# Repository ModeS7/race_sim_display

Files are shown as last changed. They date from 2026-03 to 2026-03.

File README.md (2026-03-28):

# Forza Horizon 4 Telemetry Dashboard — ESP32-2432S028 (CYD)

Real-time racing dashboard on the ESP32-2432S028 "Cheap Yellow Display" that receives Forza Horizon 4 UDP telemetry over WiFi and renders live data on the built-in 320x240 TFT.

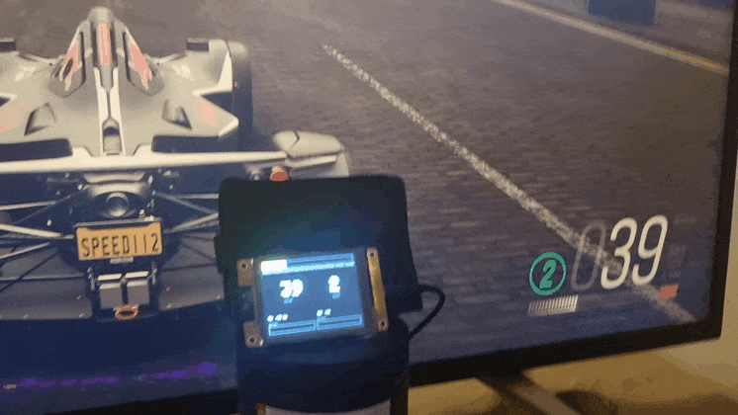
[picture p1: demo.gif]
Dashboard Demo


## Features

- **Multi-screen dashboard** — swipe left/right between screens:
  - **Race Dash** — large 7-segment gear indicator, speed, RPM bar with color zones, shift lights, position, pedal bars, lap times
  - **Data Dash** — same core layout plus large current lap timer, best/last lap comparison
  - **Lap Info** — detailed lap times, race position, speed and gear
  - **Settings** — toggle metric/imperial, adjust brightness, tune shift flash threshold, save to flash
- **Full-screen shift flash** — screen flashes red with "SHIFT!" at configurable RPM threshold, alternating with the live dashboard so you never lose data
- **7-segment gear display** — large custom-drawn gear indicator in the center of the screen
- **9-segment shift light bar** — green/yellow/red zones with configurable thresholds
- **Physical RGB LED shift light** — onboard LED mirrors the shift state (green → yellow → red → flashing)
- **Touch navigation** — tap left/right half of screen to switch between screens
- **Persistent settings** — saved to ESP32 NVS flash, survives reboots
- **Styled UI** — Race Stripe boot screen, Pit Lane animated waiting screen with scanning dots

## Hardware

- **Board**: ESP32-2432S028 (aka "Cheap Yellow Display" / CYD)
- **Display**: 2.8" 320x240 ILI9341 TFT (SPI/HSPI)
- **Touch**: XPT2046 resistive touchscreen (separate SPI/VSPI)
- **Onboard RGB LED**: pins 4 (R), 16 (G), 17 (B) — active LOW

## Setup

### 1. Install PlatformIO

If you don't have PlatformIO, install it via pip:

```bash
python -m venv .venv

# Windows
.venv\Scripts\activate

# Linux/Mac
source .venv/bin/activate

pip install platformio
```

### 2. WiFi Credentials

Copy the template and fill in your WiFi details:

```bash
cp src/wifi_credentials.h.template src/wifi_credentials.h
```

Edit `src/wifi_credentials.h`:

```cpp
#define DEFAULT_WIFI_SSID "YOUR_SSID"
#define DEFAULT_WIFI_PASS "YOUR_PASSWORD"
```

### 3. Build and Flash

Connect the CYD via USB and run:

```bash
pio run -t upload
```

If the upload fails mid-way, try a different USB cable or port. Hold the BOOT button on the CYD during upload if it won't connect.

### 4. Configure Forza Horizon 4

1. The CYD will show its IP address on the waiting screen after connecting to WiFi
2. Launch FH4, go to **Settings > HUD & Gameplay**
3. Scroll to **Data Out**
4. Set **Data Out** to **ON**
5. Set **Data Out IP Address** to the IP shown on the CYD
6. Set **Data Out Port** to `5300`
7. Start driving — the dashboard appears automatically

## Project Structure

```
src/
  main.cpp              - Setup, WiFi, screen manager, boot/waiting screens
  telemetry.h/cpp       - UDP listener, FH4 packet parsing, TelemetryData struct
  display.h/cpp         - TFT init, LED control, page dots, ScreenBase interface
  touch.h/cpp           - XPT2046 touch on VSPI, debounced edge detection
  settings.h/cpp        - Persistent settings via ESP32 Preferences (NVS)
  seg7.h/cpp            - Custom 7-segment digit renderer
  screen_dash.h/cpp     - Race Dash screen (gear, speed, RPM, position, pedals, laps)
  screen_dash_ext.h/cpp - Data Dash screen (adds large lap timer, best/last comparison)
  screen_laps.h/cpp     - Lap times detail screen
  screen_settings.h/cpp - Settings screen with touch controls
  wifi_credentials.h            - Your WiFi credentials (gitignored)
  wifi_credentials.h.template   - Template for credentials
```

## Troubleshooting

### Screen stays white or shows wrong colors

The CYD ships with different display driver ICs depending on the batch:

| Variant | USB Ports | Driver Flag |
|---|---|---|
| v1/v2 (most common) | 1x micro-USB | `-DILI9341_2_DRIVER` (default) |
| v3 "2USB" | micro-USB + USB-C | `-DST7789_DRIVER` |

If the display doesn't work, edit `platformio.ini` and change the driver flag, then re-flash.

### Screen shows colors but no text

Make sure the font flags are present in `platformio.ini` build_flags:

```
-DLOAD_GLCD
-DLOAD_FONT2
-DLOAD_FONT4
-DLOAD_FONT6
-DLOAD_FONT7
-DLOAD_FONT8
-DLOAD_GFXFF
```

### No telemetry data

- ESP32 and PC/Xbox must be on the **same WiFi network**
- IP and port must match what the CYD displays on the waiting screen
- FH4 only sends data while **actively driving** (race, freeroam, etc.) — it pauses in menus
- The dashboard stays visible for 20 seconds after pausing/rewinding before returning to the waiting screen

### Touch not responding

The CYD's touchscreen uses separate SPI pins from the display. If touch doesn't work:
- Verify the XPT2046_Touchscreen library is installed (should be automatic via `lib_deps`)
- The touch coordinate mapping may need calibration for your specific board — adjust the `map()` values in `src/touch.cpp`

## Shift Light Thresholds

Configurable via the Settings screen (swipe to screen 4) or by editing defaults in `src/settings.cpp`:

| Zone | Default % | On-Screen | RGB LED |
|---|---|---|---|
| Green | 75% | Segments 1-4 green | Green |
| Yellow | 85% | Segments 5-7 yellow | Yellow (R+G) |
| Red | 92% | Segments 8-9 red | Solid red |
| Flash | 90% | Full screen red + "SHIFT!" | Flashing red |

The flash threshold can be adjusted in Settings from 85% to 97%.

## Powering from a Logitech G920 Racing Wheel

You can power the CYD directly from the G920's internal 5V rail — no separate USB cable needed. The wheel's PCB exposes 5V and GND on the button connector pads.

### Step 1: Open the wheel and solder power wires

Remove the back cover of the G920 wheel (6 screws). Locate the button connector pads on the PCB and solder two wires:

- **Red wire** → 5V pad
- **White wire** → GND pad

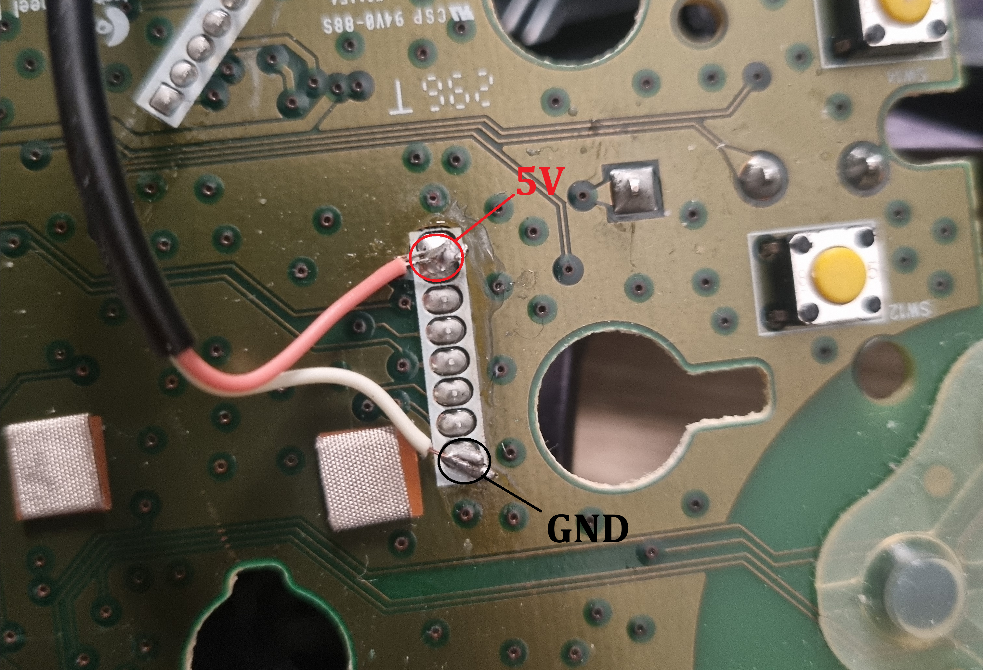
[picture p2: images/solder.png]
Solder points on G920 PCB — 5V and GND labeled


### Step 2: Route the cable out through the wheel

Feed the wires through one of the existing holes in the front face of the wheel. These OEM holes are perfect for routing a thin cable without any drilling.

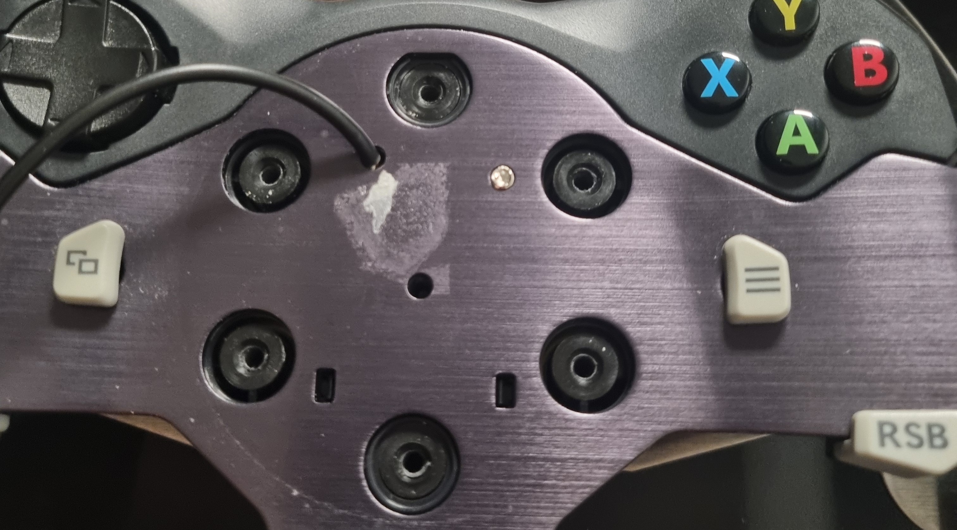
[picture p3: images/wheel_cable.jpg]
Cable routed through existing hole in the G920 wheel face


### Step 3: Mount the CYD with the 3D printed bracket

Print the bracket from the `3d/` folder (STL files included). The mount replaces the center cap on the G920 using the stock 6-bolt pattern (70mm PCD, 4.8mm holes) and extends upward into the top spoke area to hold the CYD at a natural viewing angle — similar to an F1 steering wheel display.

1. Place the **back part** of the mount over the center hub (the center cap was already removed in Step 1)
2. Connect the 5V and GND wires from Step 2 to the CYD's power pins
3. Seat the CYD into the back part
4. Press the inserts into the bolt holes to hold both parts in place
5. Place the **front part** over the CYD
6. Secure with the 6 stock center cap bolts + 4x M3x10mm screws for the CYD

### Wheel rim connector pinout (reference)

| Pin | Function |
|-----|---|
| 1 | GND |
| 2 | Button data (74HC165) |
| 3 | LED data (74HC595) |
| 4 | Clock |
| 5 | Latch |
| 6 | Parallel load |
| 7 | 5V |

## FH4 Telemetry Packet Format

The dashboard parses the 324-byte "Car Dash" UDP packet. Key offsets (FH4-specific, include the +12 byte Horizon shift):

| Offset | Type | Field |
|---|---|---|
| 0 | s32 | IsRaceOn |
| 8 | f32 | EngineMaxRpm |
| 12 | f32 | EngineIdleRpm |
| 16 | f32 | CurrentEngineRpm |
| 20 | f32 | AccelerationX |
| 24 | f32 | AccelerationY |
| 28 | f32 | AccelerationZ |
| 256 | f32 | Speed (m/s) |
| 260 | f32 | Power (watts) |
| 264 | f32 | Torque (Nm) |
| 284 | f32 | Boost (atmospheres) |
| 296 | f32 | BestLap (seconds) |
| 300 | f32 | LastLap (seconds) |
| 304 | f32 | CurrentLap (seconds) |
| 314 | u8 | RacePosition |
| 315 | u8 | Accel (0-255) |
| 316 | u8 | Brake (0-255) |
| 319 | u8 | Gear (0=R, 1-10) |

## License

MIT

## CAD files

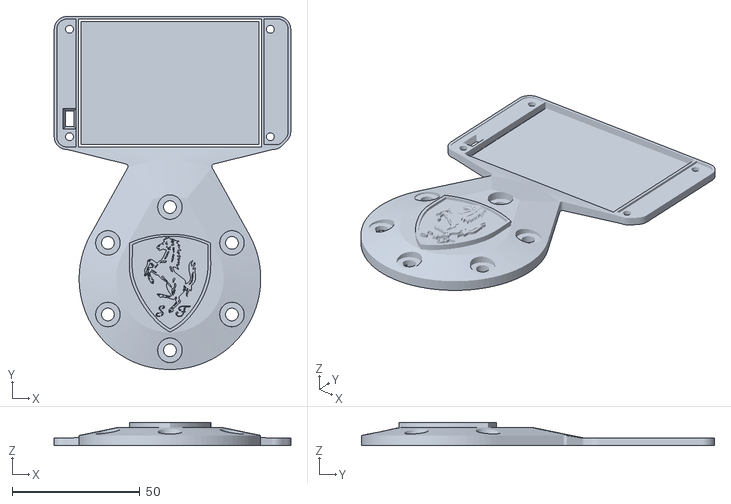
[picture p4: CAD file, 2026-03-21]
3D_mount/dash_screen_front.stl
92.5 x 138.0 x 9.11

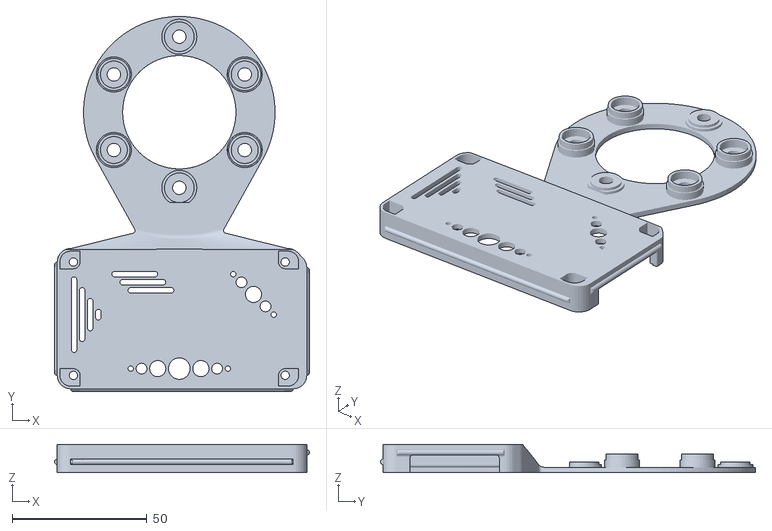
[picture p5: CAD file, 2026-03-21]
3D_mount/dash_screen_back.stl
94.5 x 139.0 x 10.5

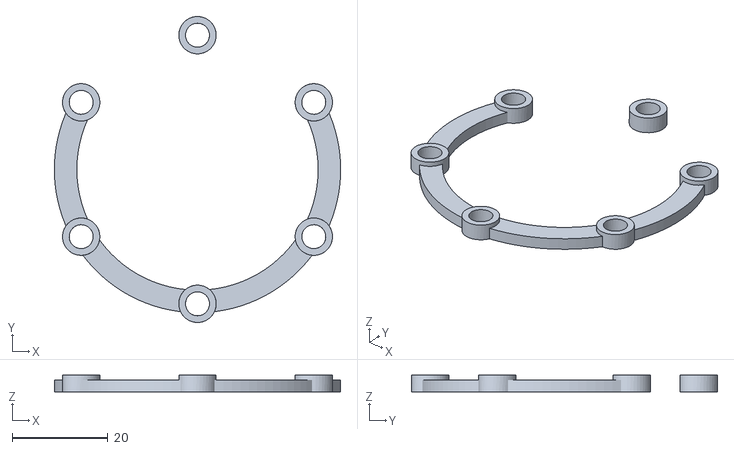
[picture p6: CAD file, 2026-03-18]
3D_mount/middle_insert.stl
59.7 x 63.8 x 3.50

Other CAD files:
3D_mount/dash_screen_back.f3d
3D_mount/dash_screen_front.f3d
3D_mount/middle_insert.f3d

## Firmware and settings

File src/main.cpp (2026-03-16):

#include <Arduino.h>
#include <WiFi.h>
#include "soc/soc.h"
#include "soc/rtc_cntl_reg.h"
#include "telemetry.h"
#include "display.h"
#include "touch.h"
#include "settings.h"
#include "screen_dash.h"
#include "screen_dash_ext.h"
#include "screen_laps.h"
#include "screen_settings.h"

// ── Screens ─────────────────────────────────────────────────────────────────
DashScreen      screenDash;
DashExtScreen   screenDashExt;
LapsScreen      screenLaps;
SettingsScreen  screenSettings;

ScreenBase* screens[] = { &screenDash, &screenDashExt, &screenLaps, &screenSettings };
const int NUM_SCREENS = 4;
int currentScreenIdx = 0;

// ── App state ───────────────────────────────────────────────────────────────
enum AppState { STATE_CONNECTING, STATE_WAITING, STATE_ACTIVE };
AppState appState = STATE_CONNECTING;

uint32_t lastDrawTime = 0;
uint32_t lastRaceOnTime = 0;
uint32_t waitingDotTimer = 0;
int waitingDotIdx = 0;

#define FRAME_INTERVAL_MS 33
#define RACE_OFF_TIMEOUT_MS 20000

// ── Helpers ─────────────────────────────────────────────────────────────────

void switchScreen(int newIdx) {
    screens[currentScreenIdx]->leave();
    currentScreenIdx = newIdx;
    screens[currentScreenIdx]->enter();
    drawPageDots(currentScreenIdx, NUM_SCREENS);
}

// ── Concept 4: Race Stripe — Boot/Connecting Screen ─────────────────────────
void drawConnectingScreen() {
    tft.fillScreen(TFT_BLACK);

    // Top and bottom red bars
    tft.fillRect(0, 0, 320, 6, TFT_RED);
    tft.fillRect(0, 234, 320, 6, TFT_RED);

    // Diagonal stripes
    uint16_t stripeCol = 0x1082;
    for (int i = 0; i < 3; i++) {
        int sx = 60 + i * 100;
        tft.fillTriangle(sx, 20, sx + 30, 20, sx + 10, 90, stripeCol);
        tft.fillTriangle(sx + 30, 20, sx + 10, 90, sx + 40, 90, stripeCol);
    }
    for (int i = 0; i < 3; i++) {
        int sx = 60 + i * 100;
        tft.fillTriangle(sx + 10, 145, sx + 40, 145, sx + 30, 215, stripeCol);
        tft.fillTriangle(sx + 40, 145, sx + 30, 215, sx + 60, 215, stripeCol);
    }

    // Title
    tft.setTextDatum(MC_DATUM);
    tft.setTextSize(3);
    tft.setTextColor(TFT_WHITE, TFT_BLACK);
    tft.drawString("FORZA", 160, 105);
    tft.setTextColor(TFT_RED, TFT_BLACK);
    tft.drawString("DASH", 160, 132);

    // Status
    tft.setTextSize(1);
    tft.setTextColor(TFT_DARKGREY, TFT_BLACK);
    tft.drawString("Connecting WiFi...", 160, 220);
}

void drawWifiFailed() {
    tft.fillScreen(TFT_BLACK);
    tft.fillRect(0, 0, 320, 6, TFT_RED);
    tft.fillRect(0, 234, 320, 6, TFT_RED);

    tft.setTextDatum(MC_DATUM);
    tft.setTextSize(3);
    tft.setTextColor(TFT_RED, TFT_BLACK);
    tft.drawString("WiFi FAILED", 160, 100);
    tft.setTextSize(1);
    tft.setTextColor(TFT_DARKGREY, TFT_BLACK);
    tft.drawString("Check SSID/password and reboot", 160, 140);
}

// ── Concept 1: Pit Lane — Waiting for Telemetry Screen ──────────────────────
void drawWaitingScreen() {
    tft.fillScreen(TFT_BLACK);

    // Cyan horizontal rules
    tft.drawFastHLine(20, 50, 280, TFT_CYAN);
    tft.drawFastHLine(20, 52, 280, TFT_CYAN);

    // Title
    tft.setTextDatum(MC_DATUM);
    tft.setTextSize(3);
    tft.setTextColor(TFT_WHITE, TFT_BLACK);
    tft.drawString("FORZA DASH", 160, 75);

    tft.drawFastHLine(20, 98, 280, TFT_CYAN);
    tft.drawFastHLine(20, 100, 280, TFT_CYAN);

    // Scanning dots (initial state)
    for (int i = 0; i < 4; i++) {
        int cx = 130 + i * 20;
        tft.drawCircle(cx, 120, 4, TFT_CYAN);
    }
    waitingDotIdx = 0;
    waitingDotTimer = millis();

    // Subtitle
    tft.setTextSize(1);
    tft.setTextColor(TFT_DARKGREY, TFT_BLACK);
    tft.drawString("Waiting for telemetry...", 160, 140);

    // IP box
    tft.drawRoundRect(60, 155, 200, 24, 4, TFT_CYAN);
    tft.setTextColor(TFT_CYAN, TFT_BLACK);
    String ipStr = WiFi.localIP().toString() + ":" + String(g_settings.udpPort);
    tft.drawString(ipStr, 160, 167);

    // Instructions
    tft.setTextColor(TFT_DARKGREY, TFT_BLACK);
    tft.drawString("Settings > HUD & Gameplay > Data Out", 160, 195);
}

void updateWaitingDots() {
    uint32_t now = millis();
    if (now - waitingDotTimer < 300) return;
    waitingDotTimer = now;

    // Clear previous dot
    int prevCx = 130 + waitingDotIdx * 20;
    tft.fillCircle(prevCx, 120, 4, TFT_BLACK);
    tft.drawCircle(prevCx, 120, 4, TFT_CYAN);

    // Advance
    waitingDotIdx = (waitingDotIdx + 1) % 4;

    // Fill current dot
    int cx = 130 + waitingDotIdx * 20;
    tft.fillCircle(cx, 120, 4, TFT_CYAN);
}

// ── Concept 3: Grid Menu — Screen Selection ─────────────────────────────────
#define MENU_BW 145
#define MENU_BH 90
#define MENU_X1 8
#define MENU_X2 167
#define MENU_Y1 28
#define MENU_Y2 124

void drawGridMenu() {
    tft.fillScreen(TFT_BLACK);

    // Header bar
    tft.fillRect(0, 0, 320, 22, 0x2104);
    tft.setTextDatum(TL_DATUM);
    tft.setTextSize(1);
    tft.setTextColor(TFT_WHITE, 0x2104);
    tft.drawString("FORZA DASH", 6, 7);
    tft.setTextDatum(TR_DATUM);
    tft.setTextColor(TFT_CYAN, 0x2104);
    String ip = WiFi.localIP().toString();
    tft.drawString(ip, 314, 7);

    // Box 1: DASHBOARD
    tft.drawRoundRect(MENU_X1, MENU_Y1, MENU_BW, MENU_BH, 6, TFT_CYAN);
    tft.fillTriangle(MENU_X1 + 55, MENU_Y1 + 20, MENU_X1 + 45, MENU_Y1 + 55,
                     MENU_X1 + 65, MENU_Y1 + 55, TFT_GREEN);
    tft.fillRect(MENU_X1 + 70, MENU_Y1 + 25, 8, 35, TFT_RED);
    tft.fillRect(MENU_X1 + 82, MENU_Y1 + 35, 8, 25, TFT_YELLOW);
    tft.setTextDatum(MC_DATUM);
    tft.setTextSize(1);
    tft.setTextColor(TFT_WHITE, TFT_BLACK);
    tft.drawString("DASHBOARD", MENU_X1 + MENU_BW / 2, MENU_Y1 + MENU_BH - 10);

    // Box 2: TELEMETRY
    tft.drawRoundRect(MENU_X2, MENU_Y1, MENU_BW, MENU_BH, 6, TFT_DARKGREY);
    tft.drawFastHLine(MENU_X2 + 40, MENU_Y1 + 55, 65, TFT_DARKGREY);
    tft.drawFastVLine(MENU_X2 + 40, MENU_Y1 + 20, 35, TFT_DARKGREY);
    tft.drawLine(MENU_X2 + 45, MENU_Y1 + 50, MENU_X2 + 60, MENU_Y1 + 30, TFT_CYAN);
    tft.drawLine(MENU_X2 + 60, MENU_Y1 + 30, MENU_X2 + 75, MENU_Y1 + 40, TFT_CYAN);
    tft.drawLine(MENU_X2 + 75, MENU_Y1 + 40, MENU_X2 + 95, MENU_Y1 + 25, TFT_CYAN);
    tft.setTextColor(TFT_WHITE, TFT_BLACK);
    tft.drawString("TELEMETRY", MENU_X2 + MENU_BW / 2, MENU_Y1 + MENU_BH - 10);

    // Box 3: LAPS
    tft.drawRoundRect(MENU_X1, MENU_Y2, MENU_BW, MENU_BH, 6, TFT_DARKGREY);
    for (int i = 0; i < 3; i++) {
        int ly = MENU_Y2 + 20 + i * 16;
        tft.fillCircle(MENU_X1 + 40, ly + 3, 2, TFT_GREEN);
        tft.drawFastHLine(MENU_X1 + 48, ly + 2, 50, TFT_DARKGREY);
    }
    tft.setTextColor(TFT_WHITE, TFT_BLACK);
    tft.drawString("LAPS", MENU_X1 + MENU_BW / 2, MENU_Y2 + MENU_BH - 10);

    // Box 4: SETTINGS
    tft.drawRoundRect(MENU_X2, MENU_Y2, MENU_BW, MENU_BH, 6, TFT_DARKGREY);
    int gcx = MENU_X2 + MENU_BW / 2, gcy = MENU_Y2 + 40;
    tft.drawCircle(gcx, gcy, 12, TFT_DARKGREY);
    tft.drawCircle(gcx, gcy, 6, TFT_WHITE);
    for (int a = 0; a < 360; a += 45) {
        float rad = a * DEG_TO_RAD;
        int tx = gcx + (int)(15 * cos(rad));
        int ty = gcy + (int)(15 * sin(rad));
        tft.fillRect(tx - 2, ty - 2, 4, 4, TFT_WHITE);
    }
    tft.setTextColor(TFT_WHITE, TFT_BLACK);
    tft.drawString("SETTINGS", MENU_X2 + MENU_BW / 2, MENU_Y2 + MENU_BH - 10);
}

int handleMenuTouch(int tx, int ty) {
    // Returns screen index (0-3) or -1 if no box hit
    if (ty >= MENU_Y1 && ty < MENU_Y1 + MENU_BH) {
        if (tx >= MENU_X1 && tx < MENU_X1 + MENU_BW) return 0;  // Dashboard
        if (tx >= MENU_X2 && tx < MENU_X2 + MENU_BW) return 1;  // Telemetry
    }
    if (ty >= MENU_Y2 && ty < MENU_Y2 + MENU_BH) {
        if (tx >= MENU_X1 && tx < MENU_X1 + MENU_BW) return 2;  // Laps
        if (tx >= MENU_X2 && tx < MENU_X2 + MENU_BW) return 3;  // Settings
    }
    return -1;
}

// ── Setup ───────────────────────────────────────────────────────────────────

void setup() {
    WRITE_PERI_REG(RTC_CNTL_BROWN_OUT_REG, 0);  // Disable brownout detector
    setCpuFrequencyMhz(80);                       // 80MHz = less current, WiFi still works

    Serial.begin(115200);
    settingsLoad();
    displayInit();
    touchInit();

    drawConnectingScreen();

    WiFi.mode(WIFI_STA);
    WiFi.begin(g_settings.wifiSSID, g_settings.wifiPass);

    uint32_t wifiStart = millis();
    while (WiFi.status() != WL_CONNECTED) {
        if (millis() - wifiStart > 15000) {
            drawWifiFailed();
            Serial.println("WiFi connection failed!");
            while (true) { delay(1000); }
        }
        delay(250);
    }

    Serial.print("Connected! IP: ");
    Serial.println(WiFi.localIP());

    // Lower WiFi TX power to reduce current spikes
    WiFi.setTxPower(WIFI_POWER_8_5dBm);
    WiFi.setSleep(true);  // Enable modem sleep between packets

    telemetryInit(g_settings.udpPort);

    appState = STATE_WAITING;
    drawWaitingScreen();
}

// ── Loop ────────────────────────────────────────────────────────────────────

void loop() {
    uint32_t now = millis();
    if (now - lastDrawTime < FRAME_INTERVAL_MS) return;
    lastDrawTime = now;

    TelemetryData data = telemetrySnapshot();

    // ── Waiting state (Pit Lane screen) ─────────────────────────────────
    if (appState == STATE_WAITING) {
        updateWaitingDots();
        if (data.isRaceOn == 1) {
            appState = STATE_ACTIVE;
            lastRaceOnTime = now;
            currentScreenIdx = 0;
            screens[0]->enter();
            drawPageDots(0, NUM_SCREENS);
        }
        return;
    }

    // ── Active state ────────────────────────────────────────────────────
    if (data.isRaceOn == 1) {
        lastRaceOnTime = now;
    } else if (now - lastRaceOnTime > RACE_OFF_TIMEOUT_MS) {
        screens[currentScreenIdx]->leave();
        appState = STATE_WAITING;
        setLED(false, false, false);
        drawWaitingScreen();
        return;
    }

    // ── Touch navigation ────────────────────────────────────────────────
    int tx, ty;
    if (touchGetXY(tx, ty)) {
        if (!screens[currentScreenIdx]->handleTouch(tx, ty)) {
            if (tx < 160) {
                switchScreen((currentScreenIdx - 1 + NUM_SCREENS) % NUM_SCREENS);
            } else {
                switchScreen((currentScreenIdx + 1) % NUM_SCREENS);
            }
        }
    }

    // ── Update current screen ───────────────────────────────────────────
    screens[currentScreenIdx]->update(data);
}

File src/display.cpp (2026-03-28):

#include "display.h"
#include "settings.h"

TFT_eSPI tft = TFT_eSPI();

static uint32_t lastBrightnessUpdate = 0;
static int smoothedLight = 2048;  // start mid-range

void displayInit() {
    pinMode(LED_R, OUTPUT);
    pinMode(LED_G, OUTPUT);
    pinMode(LED_B, OUTPUT);
    setLED(false, false, false);

    pinMode(LDR_PIN, INPUT);
    analogReadResolution(12);

    tft.init();
    tft.setRotation(1);
    tft.invertDisplay(true);
    tft.fillScreen(TFT_BLACK);

    ledcSetup(0, 5000, 8);
    ledcAttachPin(TFT_BL, 0);
    ledcWrite(0, g_settings.brightness);
}

void setLED(bool r, bool g, bool b) {
    digitalWrite(LED_R, r ? LOW : HIGH);
    digitalWrite(LED_G, g ? LOW : HIGH);
    digitalWrite(LED_B, b ? LOW : HIGH);
}

void updateAutoBrightness() {
    uint32_t now = millis();
    if (now - lastBrightnessUpdate < 500) return;
    lastBrightnessUpdate = now;

    int raw = analogRead(LDR_PIN);

    // Smooth with exponential moving average
    smoothedLight = (smoothedLight * 7 + raw) / 8;

    // CYD LDR: lower value = more light, higher value = darker
    // Range: ~100 (bright) to ~3800 (dark)
    int bright = map(smoothedLight, 3800, 100, 30, 255);
    if (bright < 30) bright = 30;
    if (bright > 255) bright = 255;

    ledcWrite(0, bright);

    static uint32_t lastDbg = 0;
    if (now - lastDbg > 3000) {
        lastDbg = now;
        Serial.printf("LDR raw=%d smooth=%d bright=%d\n", raw, smoothedLight, bright);
    }
}

// ── RPM bar gradient color ──────────────────────────────────────────────────
// fraction: 0.0 = left edge, 1.0 = right edge of bar
// Returns smooth green → yellow → red gradient
uint16_t rpmBarColor(float fraction) {
    uint8_t r, g, b;

    if (fraction < 0.5f) {
        // Green to Yellow (0.0 - 0.5)
        float t = fraction * 2.0f;
        r = (uint8_t)(t * 255);
        g = 255;
        b = 0;
    } else {
        // Yellow to Red (0.5 - 1.0)
        float t = (fraction - 0.5f) * 2.0f;
        r = 255;
        g = (uint8_t)((1.0f - t) * 255);
        b = 0;
    }

    // Convert to 565
    return ((r & 0xF8) << 8) | ((g & 0xFC) << 3) | (b >> 3);
}

// ── Tire temp color ──────────────────────────────────────────────────────
// Cold (<150°F) = blue, Optimal (180-250°F) = green, Hot (>280°F) = red
void tireTempUpdate(const TelemetryData& d) {
    // no-op, fixed thresholds
}

uint16_t tireTempColor(float tempF) {
    if (tempF < 100.0f) return TFT_BLUE;
    if (tempF < 150.0f) {
        float t = (tempF - 100.0f) / 50.0f;
        uint8_t g = (uint8_t)(t * 255);
        return ((0 & 0xF8) << 8) | ((g & 0xFC) << 3) | (255 >> 3);
    }
    if (tempF < 180.0f) {
        float t = (tempF - 150.0f) / 30.0f;
        uint8_t b = (uint8_t)((1.0f - t) * 255);
        return ((0 & 0xF8) << 8) | ((255 & 0xFC) << 3) | (b >> 3);
    }
    if (tempF <= 250.0f) return TFT_GREEN;
    if (tempF < 280.0f) {
        float t = (tempF - 250.0f) / 30.0f;
        uint8_t r = (uint8_t)(t * 255);
        return ((r & 0xF8) << 8) | ((255 & 0xFC) << 3) | (0 >> 3);
    }
    if (tempF < 320.0f) {
        float t = (tempF - 280.0f) / 40.0f;
        uint8_t g = (uint8_t)((1.0f - t) * 255);
        return ((255 & 0xF8) << 8) | ((g & 0xFC) << 3) | (0 >> 3);
    }
    return TFT_RED;
}

void drawPageDots(int currentPage, int totalPages) {
    const int dotR = 3;
    const int dotSpacing = 14;
    const int dotY = SCREEN_H - 8;
    int totalW = (totalPages - 1) * dotSpacing;
    int startX = (SCREEN_W - totalW) / 2;

    tft.fillRect(startX - dotR - 2, dotY - dotR - 1, totalW + dotR * 2 + 4, dotR * 2 + 2, TFT_BLACK);

    for (int i = 0; i < totalPages; i++) {
        int cx = startX + i * dotSpacing;
        if (i == currentPage) {
            tft.fillCircle(cx, dotY, dotR, TFT_WHITE);
        } else {
            tft.drawCircle(cx, dotY, dotR, TFT_DARKGREY);
        }
    }
}

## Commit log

2026-03-16 lower power usage
2026-03-18 3d models for the mount
    [dash_screen_back.stl, dash_screen_front.stl, middle_insert.stl]
